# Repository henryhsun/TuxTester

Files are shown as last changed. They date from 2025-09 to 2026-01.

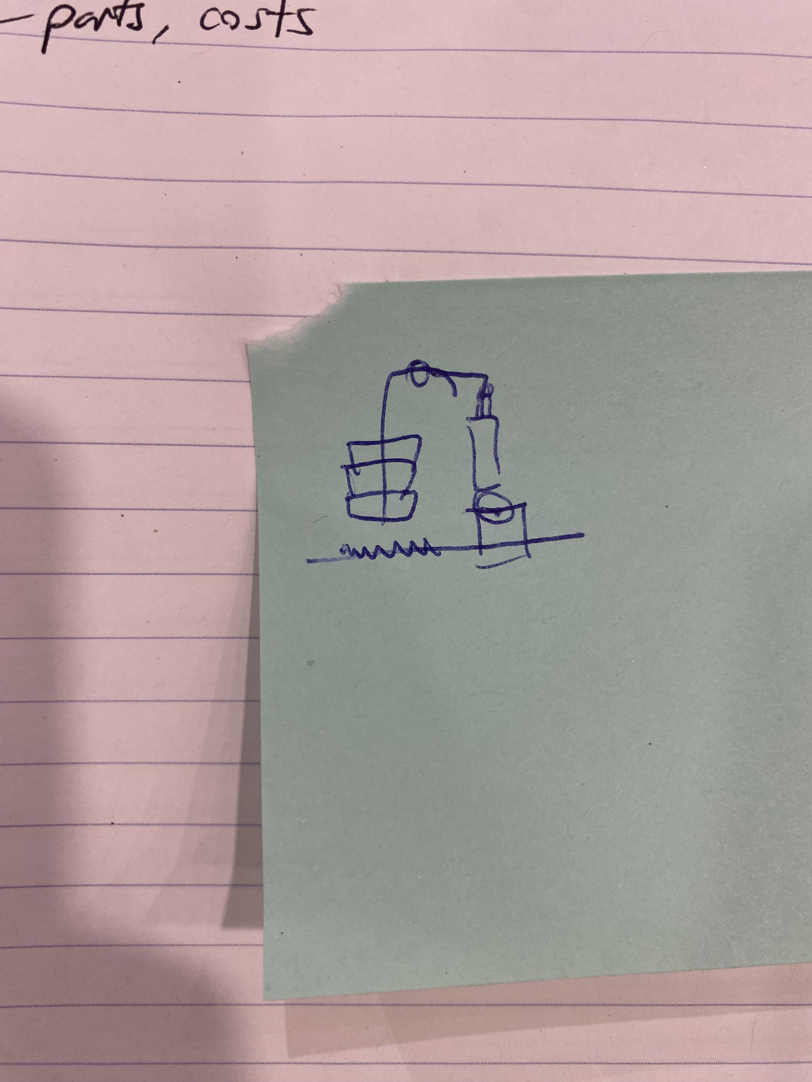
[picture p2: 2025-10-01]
04 - Media/Design Sketches/pulley_concept (1).jpeg

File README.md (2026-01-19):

Mat Wear Tester for TuxMat I designed and built as an intern over Summer 2025



**Key Features**

- Automated cyclic testing to simulate mat wear over 10,000+ cycles

- Adjustable load application up to 100 lbs

- Extruded aluminum framing, 3D printed fixtures and custom machined brackets

- Programmable test parameters: cycle count, duty cycle, PWM tuned speed

- Cycle counting and live feedback LCD

- Low-cost benchtop design (<$1000)

- Modular: 2 configurations to simulate different real-world movement patterns

- Integrated fan cooling system enabling sustained high-duty-cycle operation

- Arduino control with LCD user interface and safety shut-off loop

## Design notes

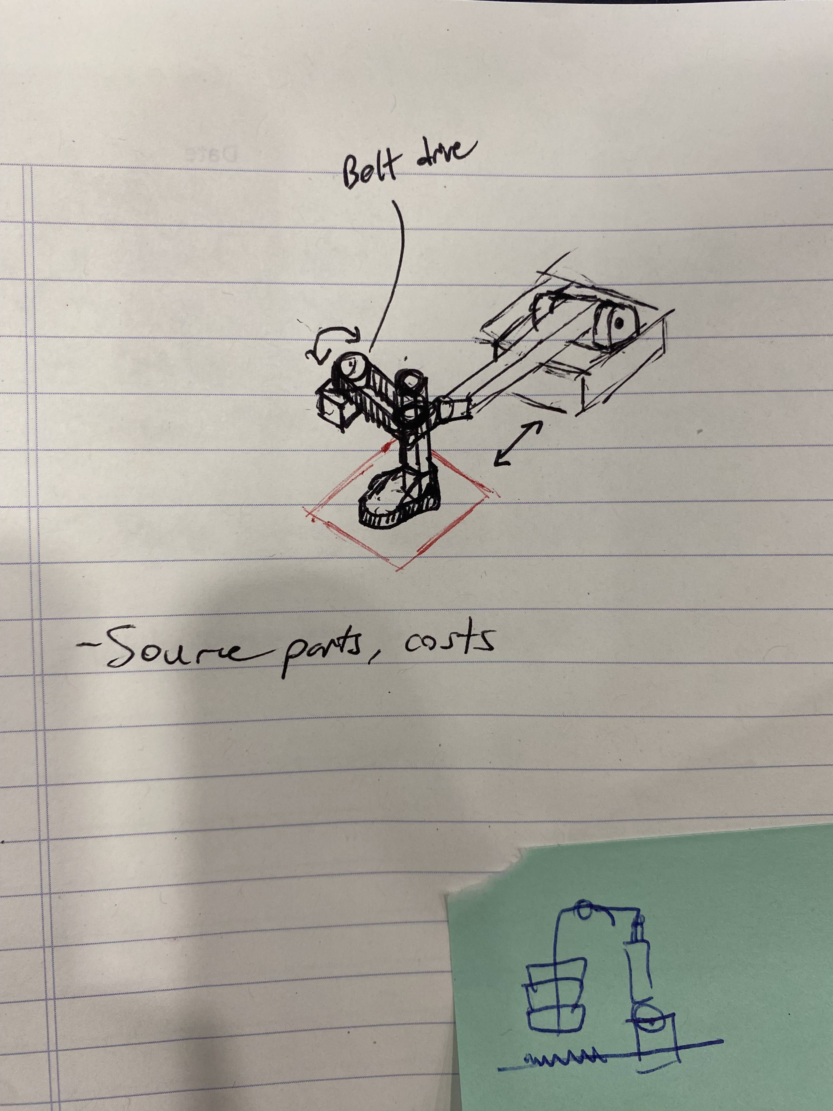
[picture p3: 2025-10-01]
04 - Media/Design Sketches/lactuator_rotation_concept.jpeg

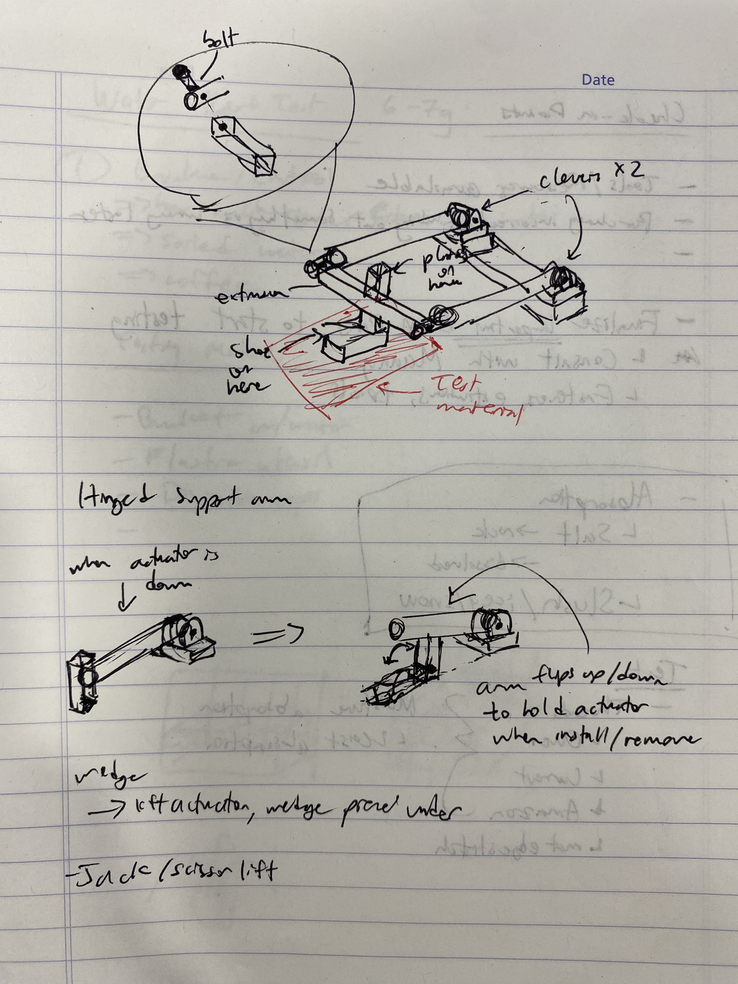
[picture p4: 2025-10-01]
04 - Media/Design Sketches/lactuator_double_concept (1).jpeg

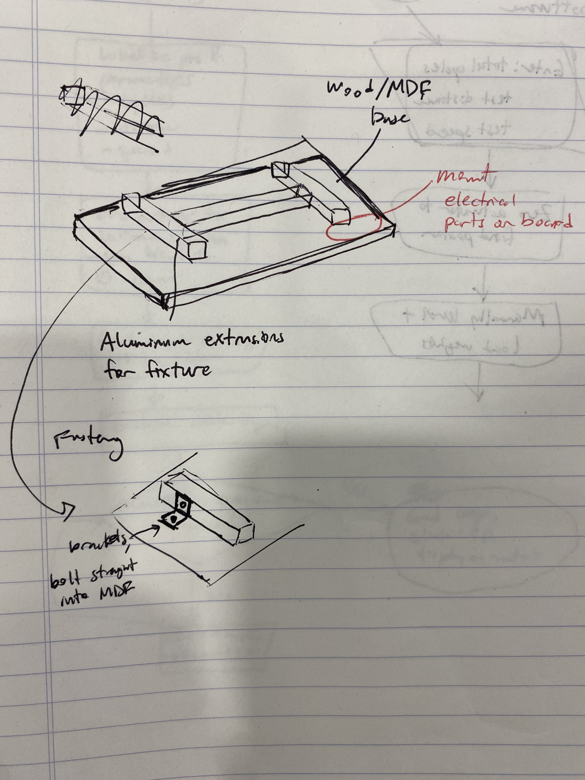
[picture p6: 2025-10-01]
04 - Media/Design Sketches/base_concept (1).jpeg

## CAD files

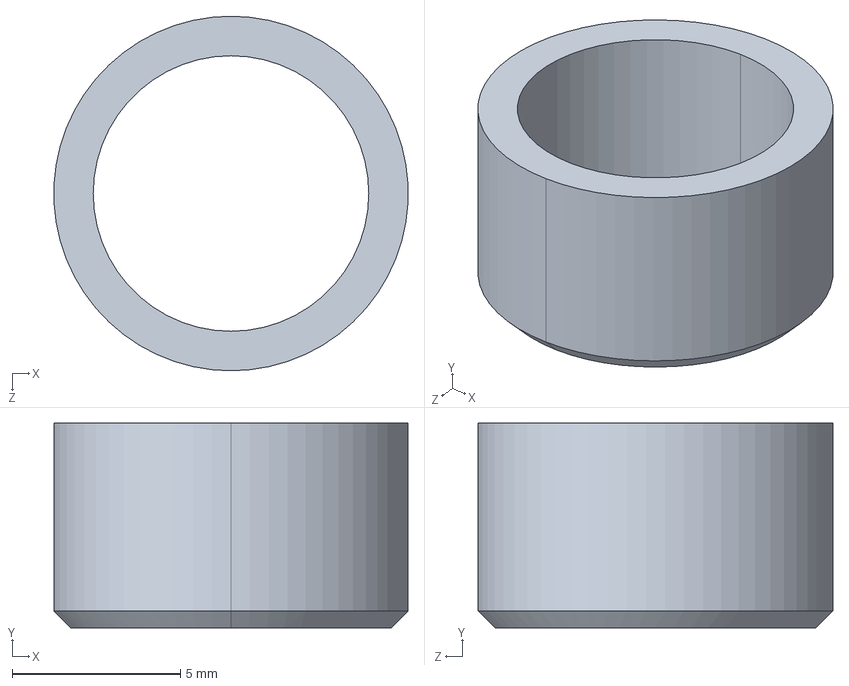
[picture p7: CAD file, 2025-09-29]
01 - Mechanical/CAD/V3..5 Revised 3D Prints and assembly/STEP/Style 2 Bushing.STEP
10.5 x 6.10 x 10.5 mm

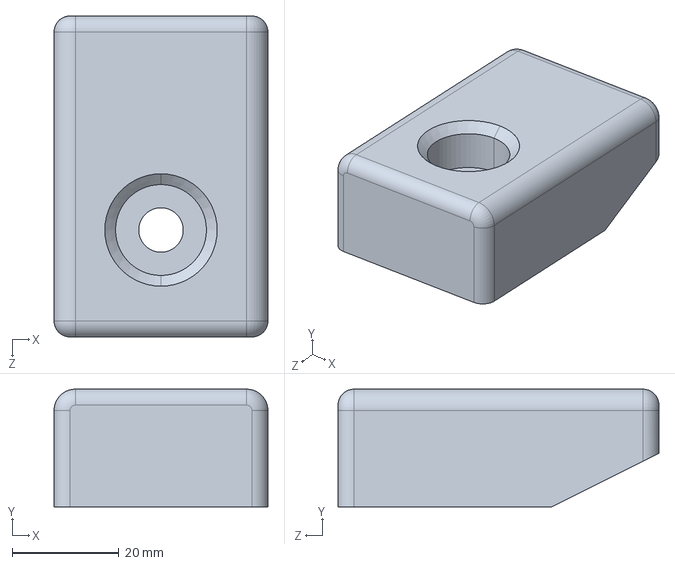
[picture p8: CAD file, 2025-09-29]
01 - Mechanical/CAD/V3..5 Revised 3D Prints and assembly/STEP/master_actuatorHolder2.STEP
40.0 x 22.0 x 60.0 mm

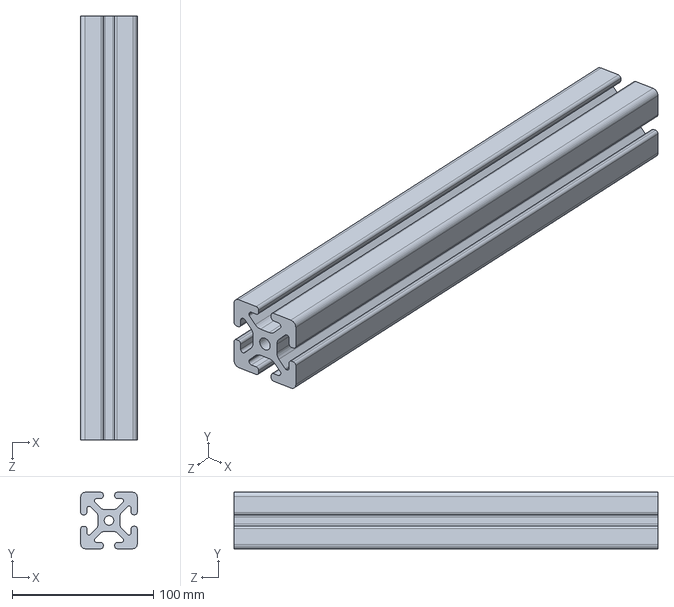
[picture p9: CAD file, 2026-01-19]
01 - Mechanical/CAD/V4 Release 1/Final1master4040 x 265.SLDPRT
40.0 x 40.0 x 300.0 mm

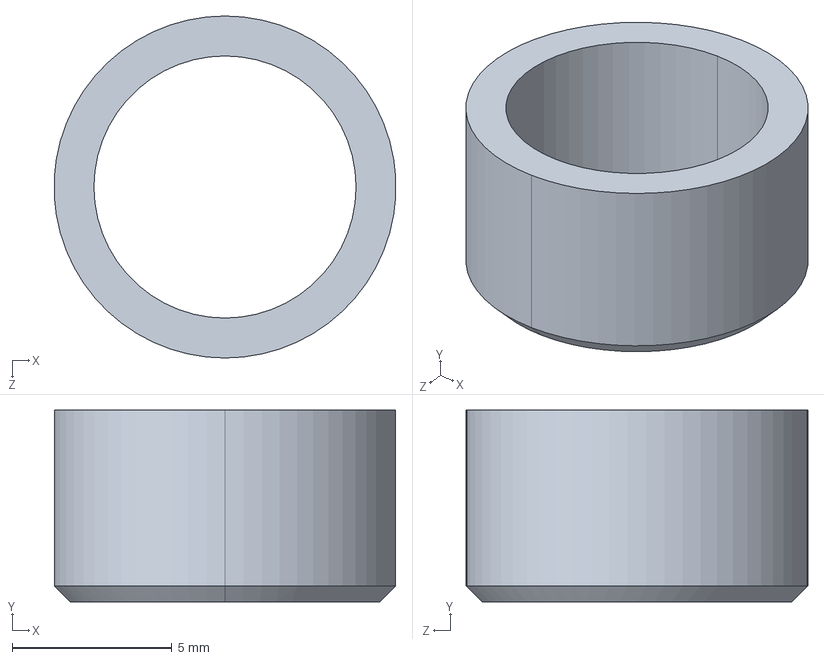
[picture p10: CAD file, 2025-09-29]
01 - Mechanical/CAD/V3..5 Revised 3D Prints and assembly/STEP/master_Hinge_Bushing.STEP
10.7 x 6.00 x 10.7 mm

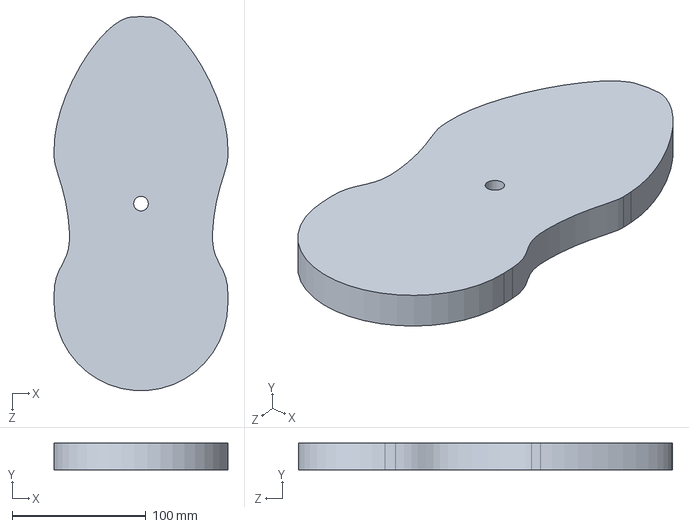
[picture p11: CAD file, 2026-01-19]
01 - Mechanical/CAD/V4 Release 1/Final1masterFoot_Sole.SLDPRT
130.0 x 20.0 x 279.8 mm

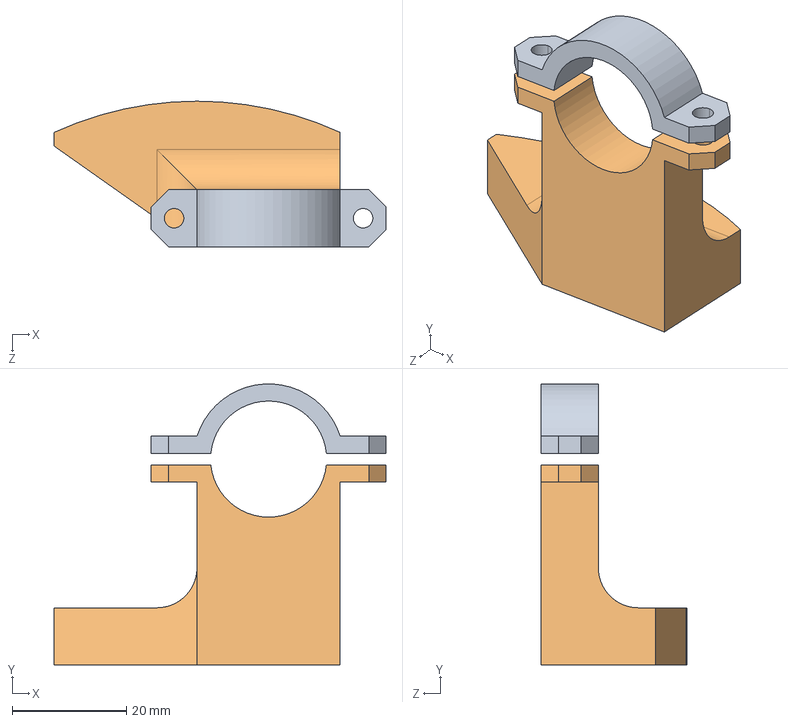
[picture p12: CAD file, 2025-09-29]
01 - Mechanical/CAD/V3..5 Revised 3D Prints and assembly/STEP/masterShaft_Clamp_Striker.STEP
58.1 x 49.1 x 25.5 mm

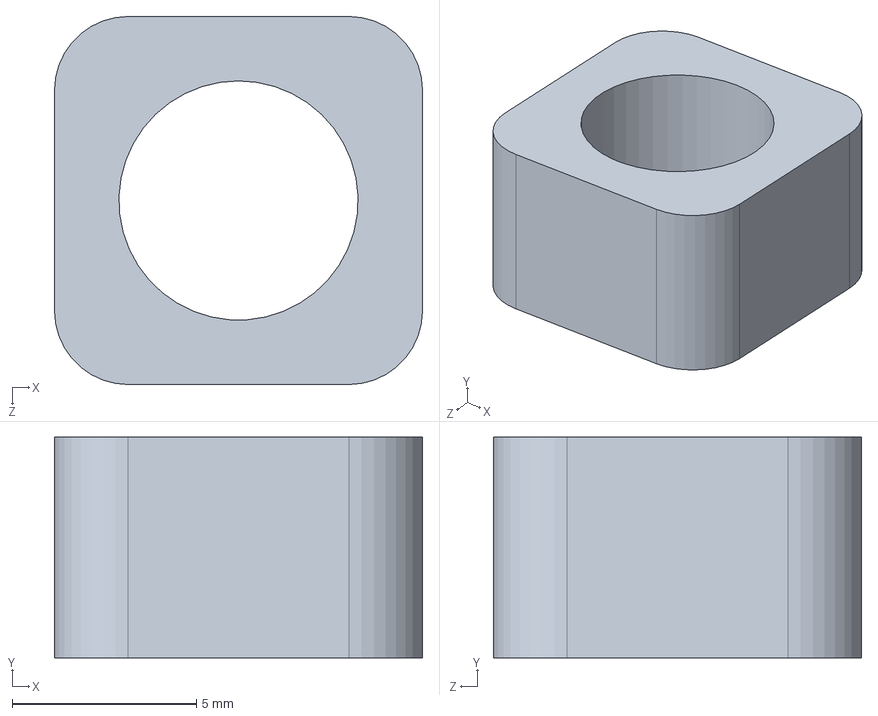
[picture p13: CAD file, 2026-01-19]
01 - Mechanical/CAD/V4 Release 1/Final1Final1rulerSpacer.SLDPRT
10.0 x 6.00 x 10.0 mm

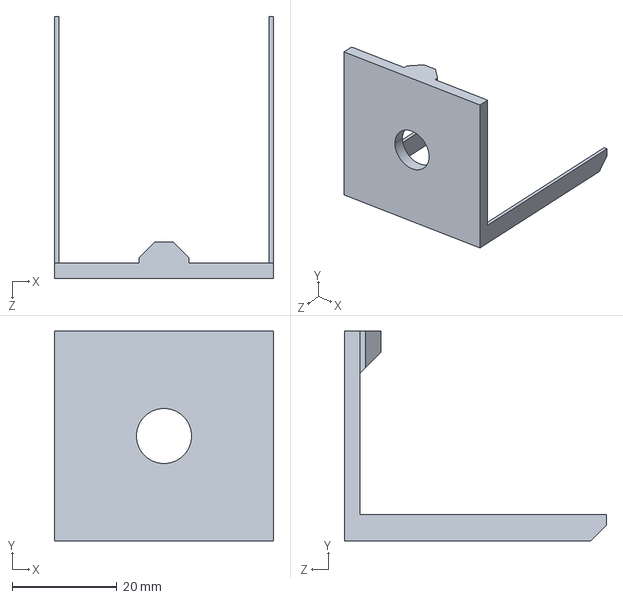
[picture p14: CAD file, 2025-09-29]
01 - Mechanical/CAD/V3..5 Revised 3D Prints and assembly/STEP/master_rulerAligner.STEP
41.8 x 40.0 x 50.0 mm

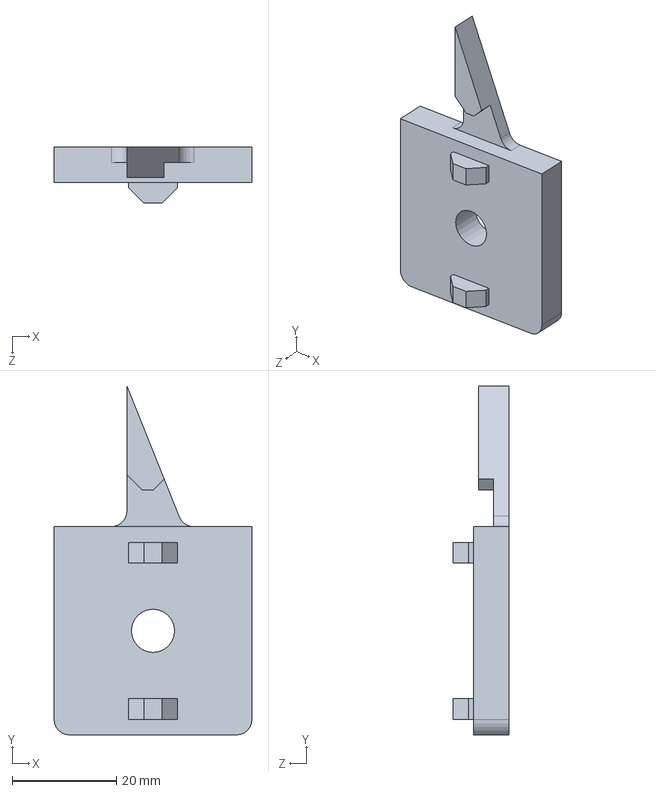
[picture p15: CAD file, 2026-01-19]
01 - Mechanical/CAD/V4 Release 1/Final1Final1rulerPointer.SLDPRT
38.0 x 67.0 x 10.8 mm

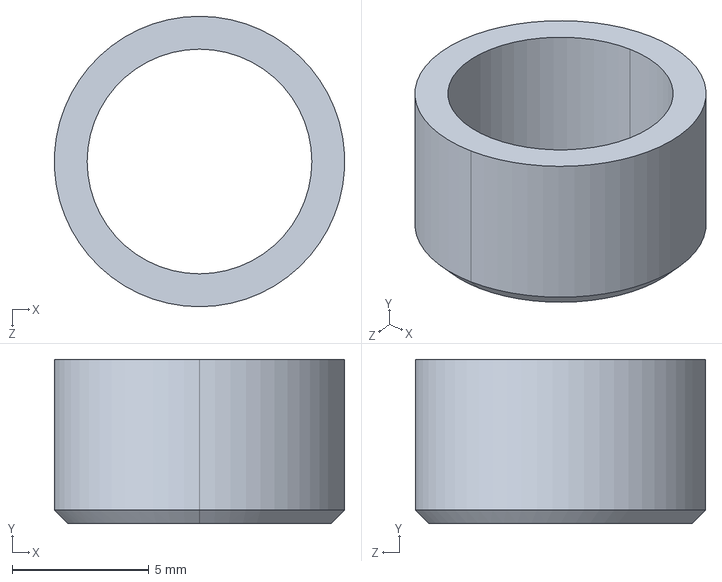
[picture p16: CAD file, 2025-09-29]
01 - Mechanical/CAD/V3..5 Revised 3D Prints and assembly/STEP/master_Hinge_Bushing2.STEP
10.6 x 6.00 x 10.6 mm

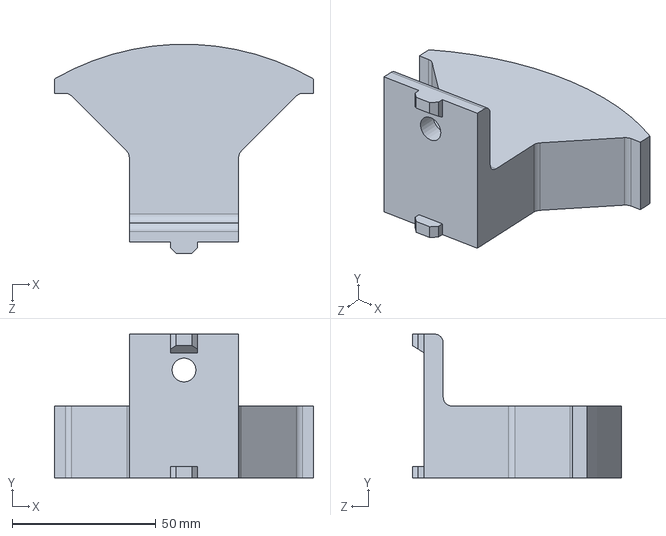
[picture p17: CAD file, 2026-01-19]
01 - Mechanical/CAD/V4 Release 1/Final1masterSwitch_Striker.SLDPRT
90.0 x 50.0 x 72.7 mm

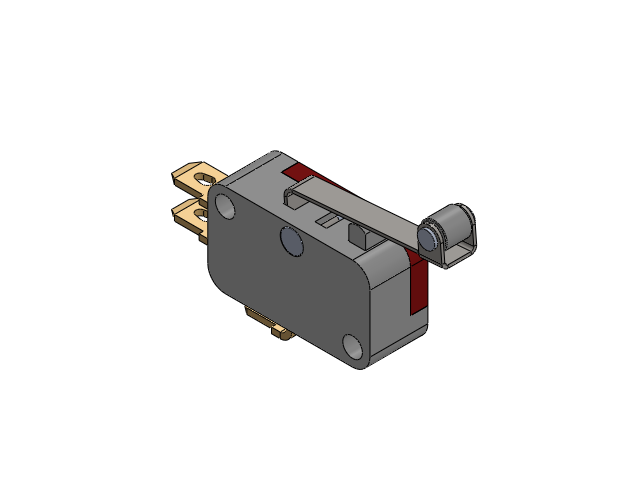
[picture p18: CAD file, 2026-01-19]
01 - Mechanical/CAD/V4 Release 1/Final1masterAssembly - V-156-1C25 micro switch.SLDASM
Final1masterBody
Final1masterCover
Final1masterConnector - straight x 2
Final1masterConnector - bent
Final1masterSwitch
Final1masterRivet - long
Final1masterArm
Final1masterRoll
Final1masterRivet - short

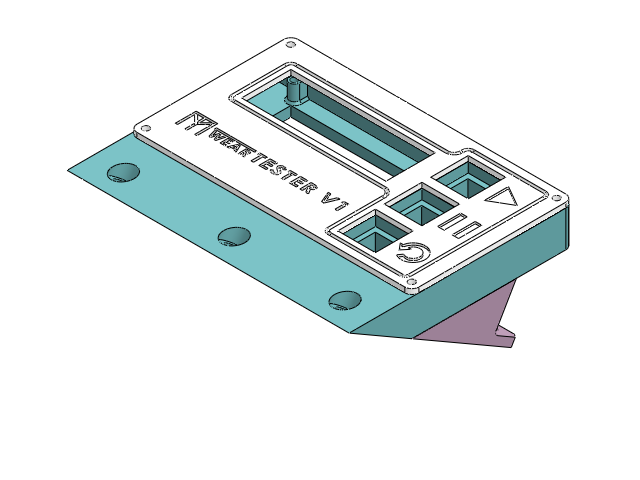
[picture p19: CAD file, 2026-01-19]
01 - Mechanical/CAD/V4 Release 1/Final1Final1console_assembly.SLDASM
Final1Final1console
Part3^Final1Final1console_assembly

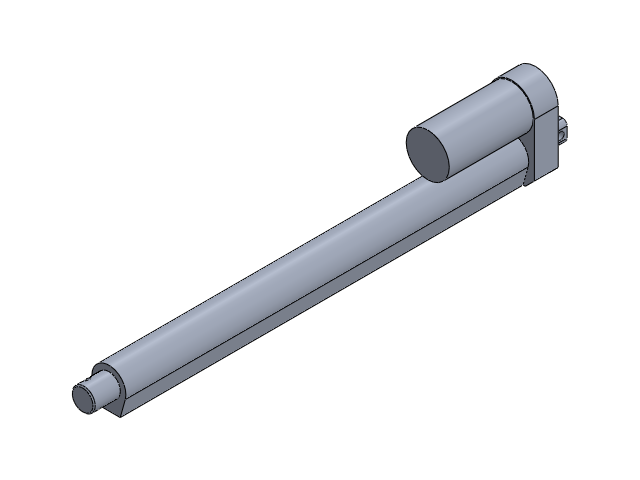
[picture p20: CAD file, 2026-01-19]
01 - Mechanical/CAD/V4 Release 1/Final1masterActuator_Assembly.SLDASM
Final1masterActuator_Body
Final1masterActuator_Shaft

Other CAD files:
01 - Mechanical/CAD/V4 Release 1/Final1Final1PSU_assembly.SLDASM
01 - Mechanical/CAD/V4 Release 1/Final1Final1Hinger.SLDASM
01 - Mechanical/CAD/V4 Release 1/plywood_distributor.SLDPRT
02 - Electrical/Schematic Drawing.dwg
01 - Mechanical/CAD/V3..5 Revised 3D Prints and assembly/STEP/masterSwitch_Actuator_Mount.STEP
01 - Mechanical/CAD/V3..5 Revised 3D Prints and assembly/STEP/masterSwitch_Mount.STEP
01 - Mechanical/CAD/V3..5 Revised 3D Prints and assembly/STEP/masterSwitch_Striker.STEP
01 - Mechanical/CAD/V3..5 Revised 3D Prints and assembly/STEP/master_Hinge_Bushing3.STEP
01 - Mechanical/CAD/V3..5 Revised 3D Prints and assembly/STEP/master_Hinge_Spacer.STEP
01 - Mechanical/CAD/V3..5 Revised 3D Prints and assembly/STEP/master_Sole Spacer.STEP
01 - Mechanical/CAD/V3..5 Revised 3D Prints and assembly/STEP/master_actuatorHolder1.STEP
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

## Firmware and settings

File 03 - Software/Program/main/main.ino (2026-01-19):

//------------------------------------------
// These parameters can be changed prior to 
// uploading code for testing
// -----------------------------------------
int testSpeed = 255; // enter value between 0 and 255
int testCycles = 3; // enter total cycles for testing
int dutyPercent = 80; // enter duty percentage between 1 and 100, higher for lower loads, lower for high loads

// ------------------------------------------
// MAT TESTER MAIN CODE
// ------------------------------------------

// include & libraries
#include <LiquidCrystal_I2C.h>
#include <Wire.h>
LiquidCrystal_I2C lcd(0x27,16,2);  // set the LCD address to 0x27 for a 16 chars and 2 line display

// global variables
int count = 0; // dont change this
int cumulativeCycles = 1; // dont change this

// motor driver pins
const int R_EN = 3;
const int L_EN = 4;
const int R_PWM = 5;
const int L_PWM = 6;

// limit switches
const int limit1 = A0;
const int limit2 = A1;

//buttons
const int startButton = A2;
const int stopButton = A3;
const int resetButton = 7;

// logic constants
const bool pressed = LOW;
const bool released = HIGH;

// timer
unsigned long startTime = 0;
unsigned long duration = 0;
float delayMultiplier = (100.0/dutyPercent) - 1.0;

// soft reset queue
bool finished = false;

// function delcarations
void calibrate();
void calibrateMessage();
void forward(int speed);
void backward(int speed);
void stop();
void checkPause();
void test();
void complete();

// -------------------------------
// xxxxxxxxx program xxxxxxxxxxxxx
// -------------------------------
void setup() 
{
Serial.begin(9600); // Don't forget this bruh

delay(200); // prevent cursed text from spawning
lcd.init();      // initialize the lcd 
lcd.backlight(); // turn on backlight
lcd.clear();

 //pinModes
pinMode(R_EN, OUTPUT);
pinMode(R_PWM, OUTPUT);
pinMode(L_EN, OUTPUT);
pinMode(L_PWM, OUTPUT);
digitalWrite(R_EN, HIGH);
digitalWrite(L_EN, HIGH);

pinMode(limit1, INPUT_PULLUP);
pinMode(limit2, INPUT_PULLUP);
pinMode(startButton, INPUT_PULLUP);
pinMode(stopButton, INPUT_PULLUP);
pinMode(resetButton, INPUT_PULLUP);
}

void loop() 
{
finished = false; // soft reset queue

calibrate(); // calibrate actuator position

test(); // testing using parameters

complete(); // finished routine (flash LCD on/off)
}

//------------
// functions
//------------

void calibrate()
{
  calibrateMessage();

  lcd.clear();
  lcd.setCursor(0,0);
  lcd.print("calibrating...");

  while(digitalRead(startButton) == released)
  {}

  while(digitalRead(limit1) == released)
  {
    backward(255);
  }
  
  stop();

  lcd.clear();
  lcd.setCursor(0,0);
  lcd.print("load weight and");
  lcd.setCursor(0,1);
  lcd.print("press start (>)");
  while(digitalRead(startButton) == released)
  {}
}

void calibrateMessage()
{
  lcd.clear();
  lcd.setCursor(0,0);
  lcd.print("press start (>)");
  lcd.setCursor(0,1);
  lcd.print("to calibrate");

  while(digitalRead(startButton) == released)
  {}
}

void forward(int speed)
{
  analogWrite(R_PWM, 0);
  analogWrite(L_PWM, speed);
  delay(1);
}

void backward(int speed)
{
  analogWrite(R_PWM, speed);
  analogWrite(L_PWM, 0);
  delay(1);
}

void stop()
{
  analogWrite(R_PWM, 0);
  analogWrite(L_PWM, 0);
}

void checkPause()
{
  if(digitalRead(stopButton) == pressed)
    {
    stop();
    lcd.clear();
    lcd.setCursor(0, 0);
    lcd.print("test paused");
    lcd.setCursor(0,1);
    lcd.print("resume with (>)");

    while(digitalRead(startButton) != pressed)
    {}
  }
}

void test()
{
  while (finished == false)
  {
    for(int i=0; i < testCycles; i++)
      {
        lcd.clear();
        lcd.setCursor(0,0);
        lcd.print("test cycles: ");
        lcd.setCursor(0,1);
        lcd.print(count + 1);
        lcd.setCursor(5,1);
        lcd.print("/");
        lcd.setCursor(7,1);
        lcd.print(testCycles*cumulativeCycles);

        startTime = millis(); // timer for duty cycle
        while(digitalRead(limit2) != pressed)
        {
          checkPause();
          forward(testSpeed);
        }
        stop();
        duration = millis() - startTime;        // how long it ran
        delay(duration*delayMultiplier);                   // pause based on duty amount

        startTime = millis();
        while(digitalRead(limit1) != pressed)
        {
          checkPause();
          backward(testSpeed);
        }
        count++;
        stop();
        duration = millis() - startTime;        // how long it ran
        delay(duration*delayMultiplier);                        // pause based on duty amount
      }
      stop();
      finished = true;
  }
}

void complete()
{
  lcd.clear();
  lcd.setCursor(0,0);
  lcd.print("test complete");
  lcd.setCursor(0,1);
  lcd.print("total: ");
  lcd.setCursor(8, 1);
  lcd.print(testCycles*cumulativeCycles);

  while(finished == true)
  {
    lcd.backlight();
    delay(1500);
    lcd.noBacklight();
    delay(1500);

    if (digitalRead(resetButton) == pressed)
    {
      finished = false;
    }
  }
  lcd.backlight();
  cumulativeCycles += 1; // increment cumulative cycle counter
}

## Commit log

2025-09-29 Photo Organization
    Media Upload and File Formatting
    [Final1Component Board.SLDPRT, Final1Final145degreeBracket.SLDPRT, Final1Final1Hinge_Bushing.SLDPRT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]
2025-10-01 Electrical Design, Program Flow Chart, Design Sketches
    Inkscape files for electrical design diagram, program flow chart logic, and design concept sketches from the notebook
2025-10-06 Added adjustable duty cycle parameter
    Final revision of V1 tester code with adjustable actuator speed, duty cycle, and cycle count
2026-01-19 Assembly Tweaks for anti-rotation
    [Final1Component Board.SLDPRT, Final1Final145degreeBracket.SLDPRT, Final1Final1Hinge_Bushing.SLDPRT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]
2026-01-30 Added force distributors for mat clamp
    [plywood_distributor.SLDPRT]
